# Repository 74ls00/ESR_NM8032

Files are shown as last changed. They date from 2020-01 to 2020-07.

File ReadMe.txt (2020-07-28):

Особенности варианта.

Конденсаторы полимерные LowESR с материнской платы.

Преобразователь с 3в до 6в.
Установлена 34063 потомучто их много. При питании ниже 2.6в у ней пропадает стабилизация и снижается напряжение с повышением пульсаций, поэтому выходное около 7.5в. Далее стабилизатор 78L06 снижает до стабильных 6в.
Дроссель (L3) после 34063 обязательный для снижения пульсаций микросхемы.
Использованы элементы LR03 из за доступности. Не рекомендуется для 34063 из за их низкого напряжения. Желательно литиевый аккумулятор 3.7в. Тогда можно попробывать убрать 78L06, и перестроить преобразователь на 6в.

DA3 LM3915N работает в режиме точки, для этоко вывод 9 никуда не подключен. Для режима шкалы мощность 78L06 слишком мала.

LM3915N разрабатывалась когда ток светодиодов был больше, возможно поэтому не учтена постоянная засветка первого светодиода. Для уменьшения нулевого тока через светодиод, он закорочен через резистор R28* 2k7, сопротивление подбирается под конкретный светодиод.

Прибор NM8032 для проверки ESR электролитических конденсаторов
https://masterkit.ru/blog/articles/pribor-nm8032-dlya-proverki-esr-elektroliticheskikh-kondensatorov

https://masterkit.ru/zip/nm8032.pdf
MD5: 05FAEDD55A1C5005F3642D41380A7DFE

Об измерении ESR и доработке NM8032
https://www.sites.google.com/a/lvsystem.ru/lab/praktika/measurement/esr-meter

Обсуждение этого варианта
Собрал пробник NM8032 для проверки ESR
https://radiokot.ru/forum/viewtopic.php?f=22&t=39489&start=20

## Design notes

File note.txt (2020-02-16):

9 3.5mm

0.14в
0.2
0.3
0.44
0.56
0.7
0.82
1.02
1.23
1.71

hef4049bt

1/10    1/1

  0.1    1.3
  0.2    1.9
  0.3    2.7
  0.4    3.8
  0.5    5.3
  0.8    7.5
  1.1   10.6
  1.5   15
  2.1   21.2
  3      30

  x1
  x10
  
  ----------------
  дросседь диам 2мм, длина 4мм.
  катушка 8 на 6мм.
  
  1 100мкгн около 47вит 0.3мм
  2  11вит

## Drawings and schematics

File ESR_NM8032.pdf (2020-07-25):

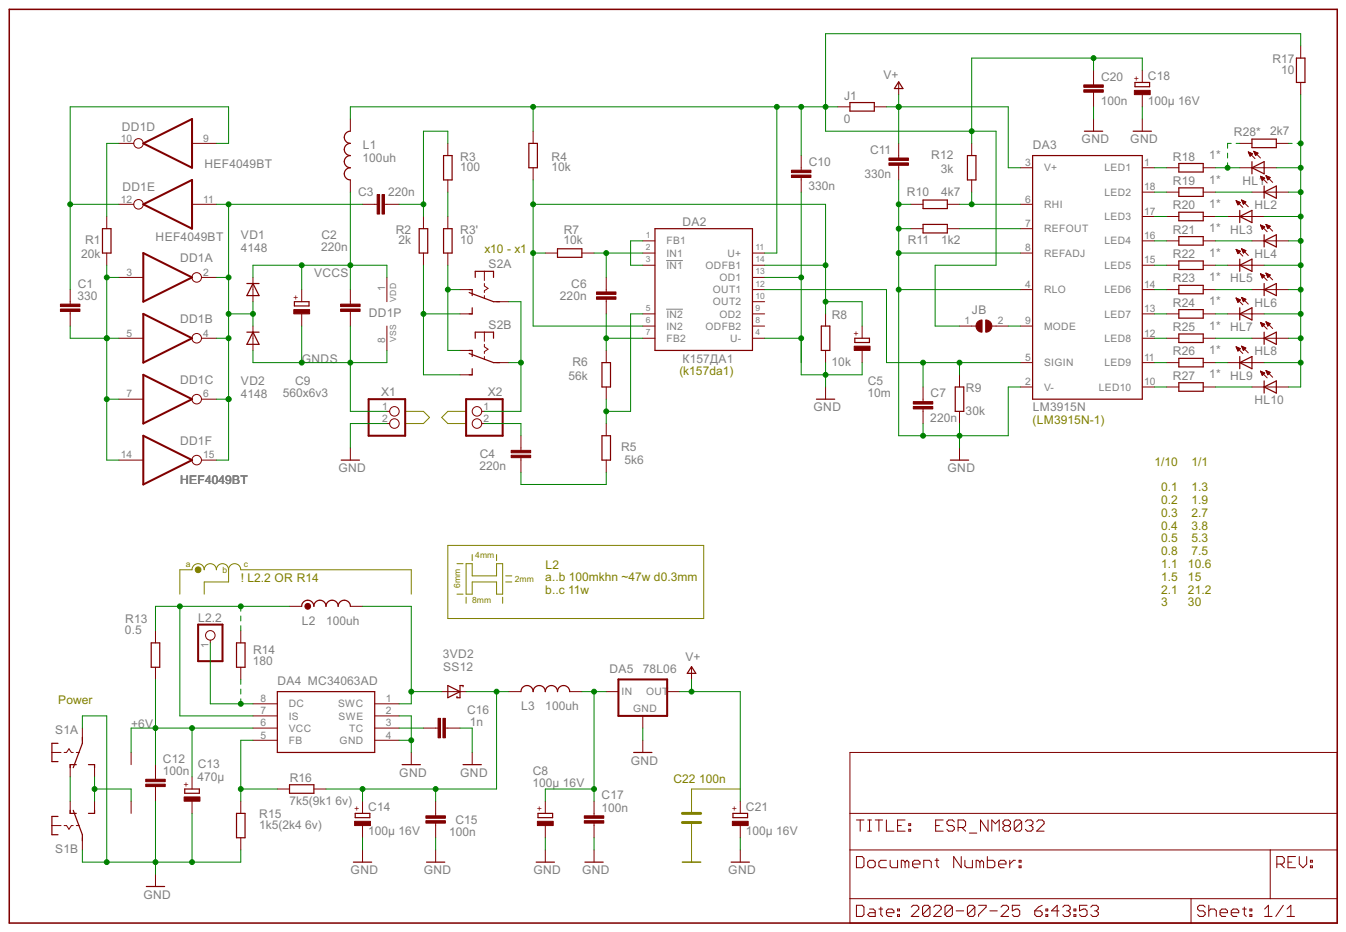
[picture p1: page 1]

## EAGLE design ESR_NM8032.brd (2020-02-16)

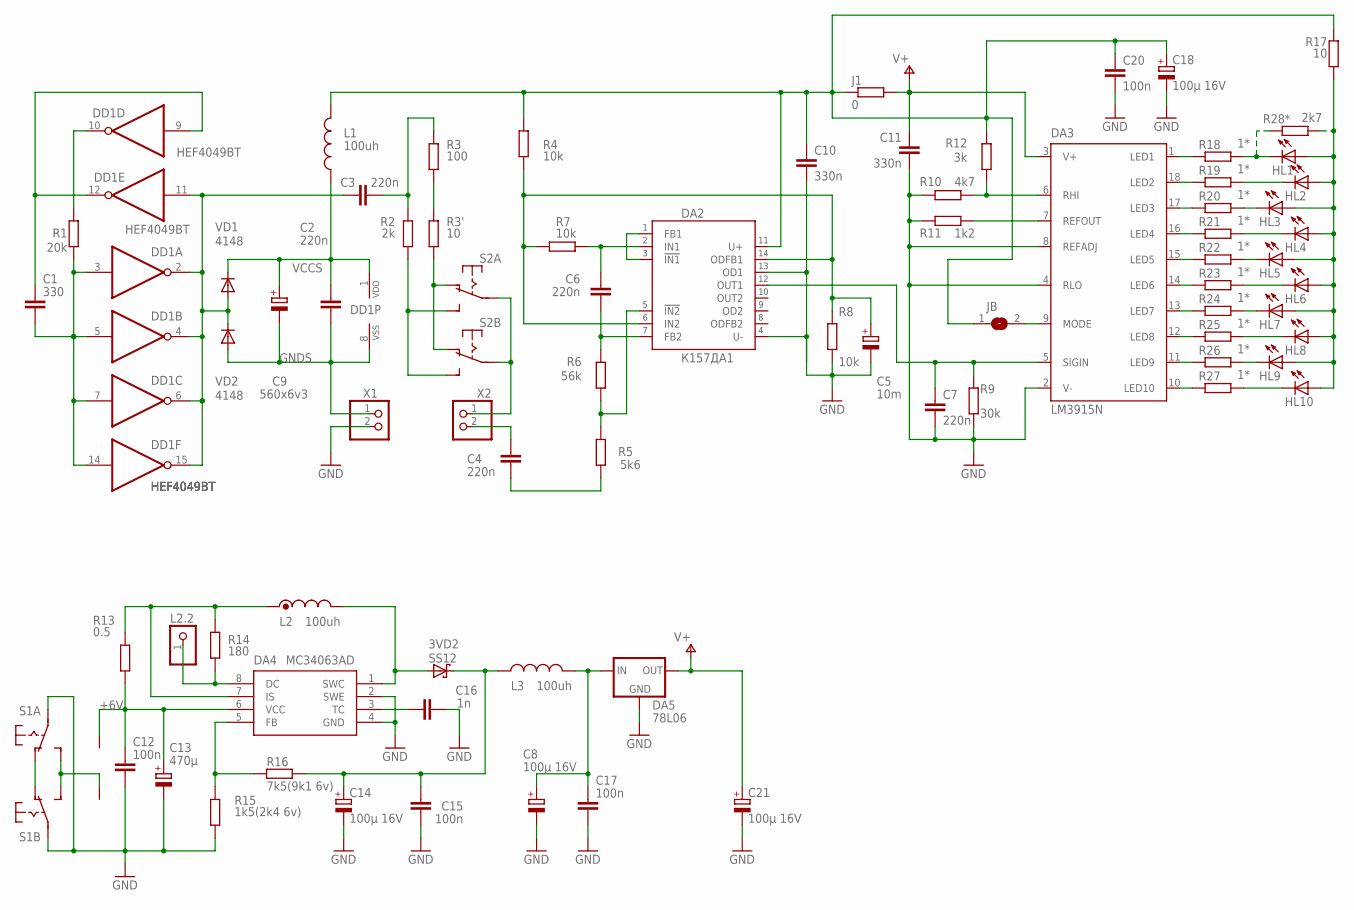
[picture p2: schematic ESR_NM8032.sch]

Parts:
3VD2: SS12; SMB
C1: 330; C0805
C2, C6: 220n; C075-032X103
C3, C4, C7: 220n; C0805
C5: 10m; E2-5
C8, C14, C18, C21: 100µ 16V; RCL_E2,5-5
C9: 560x6v3; HWPROGUSB_RCL_E3,5-8
C10, C11: 330n; C0805
C12, C15, C17, C20: 100n; C0805
C13: 470µ; RCL_E2,5-7
C16: 1n; C0805
DA2: К157ДА1; DIL14
DA3: LM3915N; DIL18
DA4: MC34063AD; SOIC8
DA5: 78L06; SOT89R
DD1: HEF4049BT; SO16
HL1, HL2, HL3, HL4, HL5, HL6, HL7, HL8, HL9, HL10: LED3MM
J1: 0; R1206W
JB: SJ
L1, L3: 100uh; 0207/10
L2: 100uh; 0204/7
L2.2: PINHD-1X1; 1X01
R1: 20k; M0805
R2: 2k; M0805
R3: 100; M0805
R3': 10; M0805
R4, R7, R8: 10k; R0805
R5: 5k6; M0805
R6: 56k; R0805
R9: 30k; R0805
R10: 4k7; R0805
R11: 1k2; R0805
R12: 3k; R0805
R13: 0.5; M1206
R14: 180; M0805
R15: 1k5(2k4 6v); M0805
R16: 7k5(9k1 6v); M0805
R17: 10; R0805
R18, R19, R20, R21, R22, R23, R24, R25, R26, R27: 1*; R0805
R28*: 2k7; R0805
S1, S2: SWITCH9X4
U$2: B-
U$4: B+
VD1, VD2: 4148; SOD80C
X1, X2: PINHD-1X2/2; 1X02

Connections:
+6V: C12.1, C13.+, DA4.6 (VCC), R13.1, U$4.P$1
GND: C5.-, C7.2, C8.-, C10.2, C11.2, C12.2, C13.-, C14.-, C15.1, C16.2, C17.2, C18.-, C20.2, C21.-, DA2.4 (U-), DA2.13 (OD1), DA3.2 (V-), DA3.4 (RLO), DA3.8 (REFADJ), DA4.2 (SWE), DA4.4 (GND), DA5.3 (GND), DA5.4 (GND), R8.1, R9.1, R10.1, R11.1, R15.1, S1.10, S1.20, X1.2
GNDS: C2.2, C9.-, DD1.8 (VSS), VD2.A, X1.1
unnamed: C1.2, DD1.3 (I), DD1.5 (I), DD1.7 (I), DD1.14 (I), R1.1
unnamed: C3.1, DD1.2 (O), DD1.4 (O), DD1.6 (O), DD1.11 (I), DD1.15 (O), VD1.A, VD2.C
unnamed: HL1.K (C), R18.2, R28*.1
unnamed: C1.1, DD1.9 (I), DD1.12 (O)
unnamed: HL2.K (C), R19.2
unnamed: DD1.10 (O), R1.2
unnamed: HL3.K (C), R20.2
unnamed: HL4.K (C), R21.2
unnamed: HL5.K (C), R22.2
unnamed: HL6.K (C), R23.2
unnamed: HL7.K (C), R24.2
unnamed: HL8.K (C), R25.2
unnamed: HL9.K (C), R26.2
unnamed: HL10.K (C), R27.2
unnamed: S2.10, S2.20, X2.1
unnamed: R3.1, R3'.2
unnamed: DA2.1 (FB1), DA2.3 (!IN1)
unnamed: C4.1, X2.2
unnamed: DA3.7 (REFOUT), R11.2
unnamed: DA3.6 (RHI), R10.2, R12.1
unnamed: C4.2, R5.1
unnamed: S1.12 (S), S1.22 (S), U$2.P$1
unnamed: C7.1, DA2.12 (OUT1), DA3.5 (SIGIN), R9.2
unnamed: S1.11 (O), S1.21 (O)
unnamed: C3.2, R2.2, R3.2
unnamed: DA3.1 (LED1), R18.1
unnamed: HL1.A, HL2.A, HL3.A, HL4.A, HL5.A, HL6.A, HL7.A, HL8.A, HL9.A, HL10.A, R17.2, R28*.2
unnamed: DA2.5 (!IN2), R5.2, R6.1
unnamed: DA4.8 (DC), L2.2.1, R14.1
unnamed: DA4.7 (IS), L2.1, R13.2, R14.2
unnamed: DA4.5 (FB), R15.2, R16.1
unnamed: 3VD2.A, DA4.1 (SWC), L2.2
unnamed: C16.1, DA4.3 (TC)
unnamed: C6.1, DA2.2 (IN1), R7.2
unnamed: C6.2, DA2.7 (FB2), R6.2
unnamed: C5.+, DA2.6 (IN2), DA2.14 (ODFB1), R4.1, R7.1, R8.2
unnamed: 3VD2.C, C14.+, C15.2, L3.1, R16.2
unnamed: DA3.18 (LED2), R19.1
unnamed: R3'.1, S2.11 (O), S2.21 (O)
unnamed: C10.1, C18.+, C20.1, DA2.11 (U+), J1.1, JB.1, L1.2, R4.2, R12.2, R17.1
unnamed: R2.1, S2.12 (S), S2.22 (S)
unnamed: DA3.17 (LED3), R20.1
unnamed: DA3.16 (LED4), R21.1
unnamed: DA3.15 (LED5), R22.1
unnamed: DA3.14 (LED6), R23.1
unnamed: DA3.13 (LED7), R24.1
unnamed: DA3.12 (LED8), R25.1
unnamed: DA3.11 (LED9), R26.1
unnamed: DA3.10 (LED10), R27.1
unnamed: DA3.9 (MODE), JB.2
unnamed: C8.+, C17.1, DA5.1 (IN), L3.2
V+: C11.1, C21.+, DA3.3 (V+), DA5.2 (OUT), J1.2
VCCS: C2.1, C9.+, DD1.1 (VDD), L1.1, VD1.C

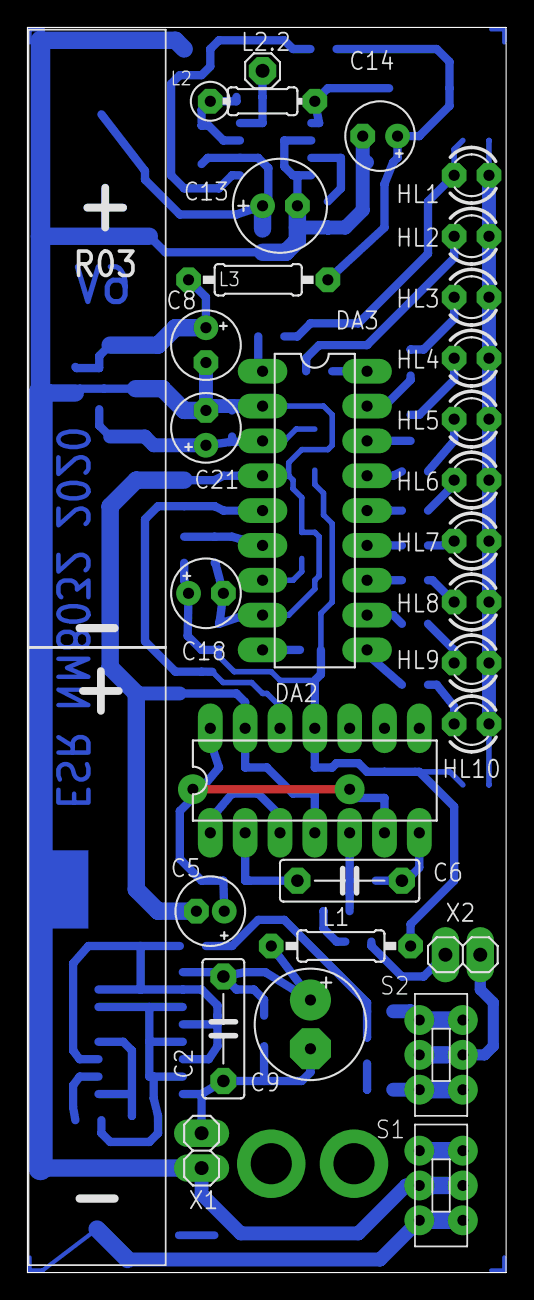
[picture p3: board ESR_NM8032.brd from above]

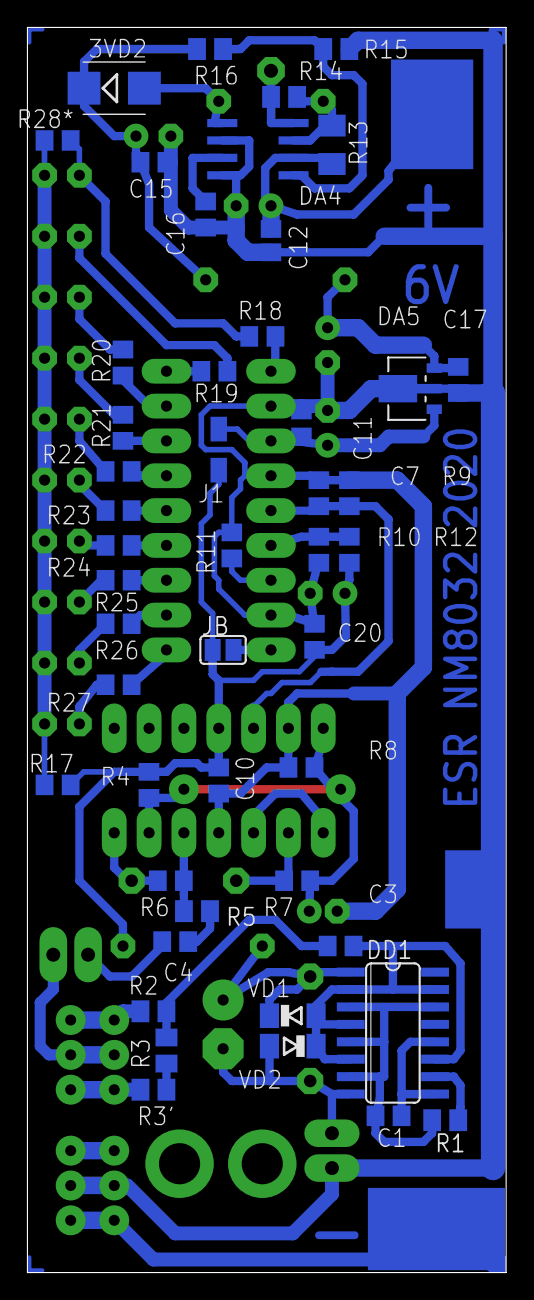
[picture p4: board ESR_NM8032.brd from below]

Board: 2 copper layers, 34.9 x 90.8 mm, 81 parts (50 on the bottom side), 56 nets.

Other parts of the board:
U$1, U$3: LR03

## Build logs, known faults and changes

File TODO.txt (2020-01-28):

поменять переключатель S2 и контакт X2

увеличить ширину R03 до 11мм

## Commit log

2020-07-19 new sch pdf
    [ESR_NM8032.sch]
2020-07-25 sch fix
    [ESR_NM8032.sch]
